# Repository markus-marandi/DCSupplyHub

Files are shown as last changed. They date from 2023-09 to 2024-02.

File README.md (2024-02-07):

# LAB DC POWER SUPPLY

## Overview

This repository is dedicated to the LAB DC POWER SUPPLY project, a comprehensive hardware solution designed to deliver a stabilized output adjustable between 0 and 30VDC with a current control range from 2 mA to 3 A.

## Key Features

- **Variable Control**: Delivering a continuously adjustable voltage between 0 to 30V and a current from 2 mA up to 3A.
- **Safety First**: Built-in overcurrent protection and short-circuit safeguards.
- **User-Friendly**: Dual LCD displays for real-time feedback, clear labeling, and precise control knobs.
- **Compact Design**: Optimized for benchtop use with dimensions.

## Documentation

For a detailed breakdown of the hardware requirements, specifications, component details, and more, refer to the [Hardware Requirements Specification](./documentation/SPECS) under the `documentation` directory.

## Components

Our project components are sourced from trusted suppliers including Farnell, TME, Mouser, and others. The list of components, along with their respective codes, can be found in the detailed specification document.

## Revision History

The project has undergone several revisions:

- **1.0** (18.09.2023): Initial Version.
- **1.1** (20.09.2023): GANTT chart.
- **1.2** (27.09.2023): Started documentation and specification.
- **1.3** (04.10.2023): Added component list.
- **1.4** (10.10.2023): Added schematics.
- **1.5** (15.10.2023): Added second version of schematics. 

For a detailed revision history, please refer to the specification document.

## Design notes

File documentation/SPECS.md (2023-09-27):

# LAB DC POWER SUPPLY
## Hardware Requirements Specification
### Version 1.1

---

### Revision History

| Date | Version | Description | Author |
|---|---|---|---|
| 18.09.2023 | 1.0 | Initial Version | Markus Marandi|
| 20.09.2023 | 1.1 | Added GANTT chart | Markus Marandi|

---

## Table of Contents

1. [Introduction](#introduction)
    - [Purpose](#purpose)
    - [Scope](#scope)
    - [Definitions, Acronyms, and Abbreviations](#definitions-acronyms-and-abbreviations)
2. [Overall Description](#overall-description)
    - [Product Perspective](#product-perspective)
    - [Product Functions and Components](#product-functions-and-components)
    - [Constraints](#constraints)
    - [Assumptions and Dependencies](#assumptions-and-dependencies)
3. [Specific Requirements](#specific-requirements)
    - [External Interface Requirements](#external-interface-requirements)
    - [Performance Requirements](#performance-requirements)
    - [Safety Requirements](#safety-requirements)
    - [Environmental Requirements](#environmental-requirements)
    - [Reliability and Durability](#reliability-and-durability)
4. [Flowchart](#flowchart)
5. [GANTT chart](#gantt-chart)

---

## 1. Introduction

This document provides a detailed technical specification for a 0-30 VDC Stabilised Power Supply with Current Control ranging from 2 mA to 3 A as a hardware project.

### 1.2 Purpose

The purpose of this specification is to offer a comprehensive and detailed description of the requirements for the 0-30V / 0-3A Bench Power Supply. It encapsulates its external behavior, functional requirements, design constraints, and other crucial details to ensure the successful design and execution of the hardware.

### 1.2 Scope

This hardware project centers on the 0-30V / 0-3A Bench Power Supply, a device proficient in delivering a continuously variable stabilized output adjustable between 0 and 30VDC. The power supply can modulate its output current from a minimal 2 mA to a maximum of 3A. This document encompasses the entirety of the hardware's functionalities, design considerations, and safety features.

### 1.3 Definitions, Acronyms, and Abbreviations

- **VDC**: Volts Direct Current
- **mA**: Milliamperes
- **A**: Amperes
- **PCB**: Printed Circuit Board
- **SRS**: Software Requirements Specification
- **PSU**: Power Supply Unit

---

## 2. Overall Description

### 2.1 Product Perspective

The 0-30V / 0-3A Bench Power Supply is envisioned to be a compact and efficient unit, suitable for diverse electronics testing and experimentation. The choice of a maximum 30V output ensures broader compatibility with prevalent electronics components and systems, simultaneously ensuring safety and affordability.

### 2.2 Product Functions and Components

- **Variable Voltage and Current Control**: Adjust the output voltage from 0 to 30V and the current from 2 mA to 3A.
- **LCD Displays**: Dual LCD displays for real-time voltage and current readings.
- **Control Knobs**: Precise control over voltage and current settings with digital potentiometers.
- **LED Indicator**: Signifies the operational status of the power supply.
- **Current Limiting and Short Circuit Protection**: Safeguards against overcurrent damage.
- **Power Switch**: An ON/OFF mechanism.
- **Microcontroller (ATmega32U4)**: Governs display and overall control.
- **Case**: Well-ventilated and heat-proof with anti-slippery feet.
- **Stadardised Connectors**: Banana plugs and binding posts.

### 2.3 Constraints

Approximate dimensions are 105 x 165 x 249 mm.

### 2.4 Assumptions and Dependencies

It's assumed that the device will be utilized in a dry environment.

---

## 3. Specific Requirements

### 3.1 External Interface Requirements

- **Input Interface**: TBD
- **Output Interface**: Connectors for DC output (0 – 30V, preferable up to 36V) and a USB connector (5V, 1A).
- **Display**: Dual-line for output voltage and current.

### 3.2 Performance Requirements

- **Voltage Stability**: Max ripple of 0.05%.
- **Current Limiting Accuracy**: Tolerance of ± 0.01A.

### 3.3 Safety Requirements

- **Overcurrent Protection**: Safeguard against potential overcurrent.
- **Thermal Management**: Prevent overheating.

### 3.4 Environmental Requirements

- **Operating Temperature**: Optimal between -10 to 40°C.
- **Humidity Tolerance**: Up to 80% relative humidity without condensation.

### 3.5 Reliability and Durability

- **Component Quality**: Ensure longevity and reliability.

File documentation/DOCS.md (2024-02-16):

### DC Supply Hub Documentation

#### Overview

The DC Supply Hub is designed to provide a configurable power supply, capable of adjusting voltage and current settings through user inputs. This system utilizes a microcontroller unit (MCU) interfaced with various components including digital potentiometers, digital-to-analog converters (DACs), and current sensors, to control and monitor the output power.

#### System Architecture

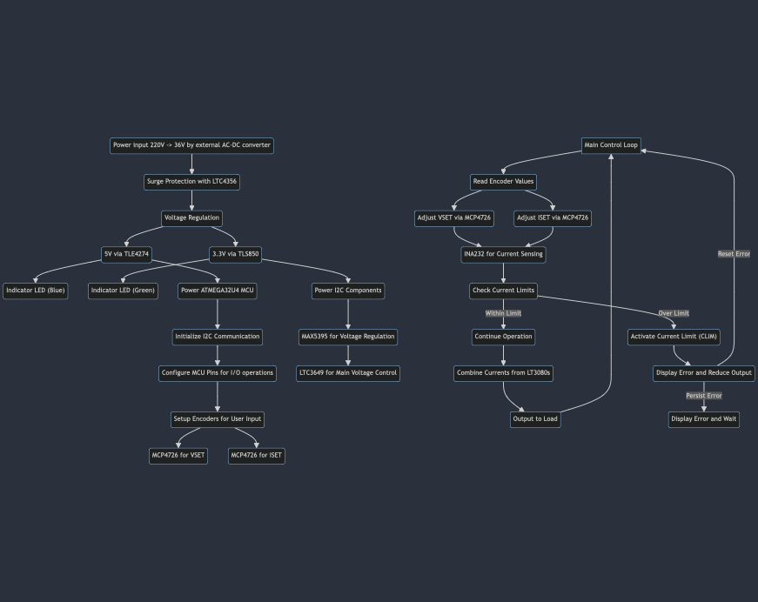
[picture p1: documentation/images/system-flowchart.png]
System Flowchart


**Components**
- **Microcontroller (MCU):** At the heart of the system is an ATMEGA32U4-AU MCU, responsible for coordinating the interactions between all peripherals and executing the firmware logic.
- **Digital Potentiometer (MAX5395NATA+T):** Used for fine-tuning the output voltage by adjusting the resistance in the feedback loop of an operational amplifier.
- **DACs (MCP4726):** Two DACs are used, one for setting the output voltage (VSET) and the other for setting the output current limit (ISET).
- **Current Sensor (INA232BIDDFR):** Provides accurate monitoring of the output current by measuring the voltage across a shunt resistor.
- **Encoders:** Two rotary encoders provide user inputs to set the desired voltage and current settings.

**I2C Addresses**
- 0x28: Digital potentiometer (MAX5395NATA+T) [U10].
- 0x30: Encoder values for voltage and current.
- 0x48: INA232BIDDFR (16-bit Current sensor).
- 0x60: MCP4726 (DAC for VSET) [U16].
- 0x63: MCP4726 (DAC for ISET) [U11].

**MCU logical I/O**
- PIN 1 (CLIM): Current limit indicator/output.
- PIN 28 (LED_MCU): LED indicator controlled by the MCU.
- PIN 36 (ADC-IOUT): Analog-to-digital converter input for measuring output current directly from the MCU.

#### Firmware Logic

Firmware Flowchart

The firmware controls the DC Supply Hub's operation, including reading encoder inputs for voltage and current settings, adjusting the output voltage and current accordingly, and monitoring the actual output current for safety and accuracy. The main components of the firmware logic include:

1. **Initialization:** Setup of I2C communication, DACs initialization, encoder input setup, and current sensor configuration.
2. **Input Processing:** Receives encoder inputs for desired voltage and current settings and updates the system settings accordingly.
3. **Output Adjustment:** Controls the digital potentiometer and DACs to adjust the output voltage and current settings based on user inputs.
4. **Current Monitoring:** Uses the INA232 current sensor to monitor the actual output current, ensuring it does not exceed the user-set limit.
5. **Safety Features:** Includes mechanisms to prevent overcurrent and overheating, such as dynamic current limiting and thermal shutdown.

#### Bill of Materials (BOM)

```markdown
| Component | Part Number | Description | Quantity |
|-----------|-------------|-------------|----------|
| D3 | SSB43L | 40V 0.45V 5A Schottky Barrier Diodes | 7 |
| ENC1, ENC2 | 440054-3 | 1x3P 2mm Male pin Wire To Board Connector | 10 |
| J2 | 2013499-1 | MICRO USB REC TYPE B DIP | 5 |
| J4 | 1757242 | 2 Bend 5.08mm 1x2P Pluggable Terminal Block | 5 |
| LED1 | CheckFuse | 0805 Red LED | 20 |
| LED2 | YELLOW | 0805 Yellow LED | - |
| LED3 | BLUE | 0805 Blue LED | - |
| LED7 | GREEN | 0805 Green LED | - |
| U5 | ATMEGA32U4-AU | 32KB Flash Microcontroller | 5 |
| D1, D2, D6 | CM1223-02SO | SOT-23-5 TVS | 15 |
| J3, J5, J6 | 61900411121 | 2x32P 2.54mm Plugin Connector | 15 |

```
### Programming the MCU

The MCU was programmed using Arduino's In-Circuit Serial Programming (ICSP) method, ensuring a reliable and efficient way to upload the firmware directly to the chip. This approach allows for direct programming of the MCU without the need for a pre-installed bootloader, providing more control over the hardware and enabling the use of the entire flash memory for the application code.

### Conclusion

The DC Supply Hub represents a sophisticated electronic design that integrates digital control with analog power management to provide a versatile and user-friendly power supply solution. The documentation provided outlines the system's architecture, key components, and firmware logic, providing a comprehensive overview for understanding and replicating the design.

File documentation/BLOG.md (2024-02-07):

# LAB DC POWER SUPPLY Development Blog

## 18.09.2023

- Created the initial version of Hardware Requirements Specification.
- Documented key features, requirements, and project scope.

## 20.09.2023

- Updated the Hardware Requirements Specification.
- Added a GANTT chart for project timeline visualization.

## 26.09.2023

- Researched FARNELL's catalogue and listed essential components.
- Finalized components' part numbers and estimated costs.

| Component | Farnell Part Number | Price (€) |
|---|---|---|
| Microcontroller (MCU) | 1748525 | €4.9 |
| 3.3V LDO Voltage Regulator | 1467779 | €0.7 |
| 5.0V LDO Voltage Regulator | 1467781 | €0.5 |
| 16MHz Crystal Oscillator | 1611806 | €0.8 |
| Push Buttons | 1821244 | €0.5 |
| Electrolytic Capacitors | 1217619, 4434778, 8767432 | €4-7 |
| Ceramic capacitors | 2320821, 1759057, 1520289 | €1-2 |
| Diodes | 2118071, 1462392, 2329772, 3230195, 1634076 | €5-7 |
| Dual LCD Display (16 x 2)  | 2675047, 2125942 | €2-4 |
| Rotary Encoders | 3769973 | €11 |
| LED Indicator, heat sink | 2065054 | €5.2 |
| Resistors | 2112111 | €6 |
| **Total** | | **€45** |

## 27.09.2023

- Initialized a GitHub repository for the project.
- Added Hardware Requirements Specification, README, and this development blog.

## 01.10.2023

- Started with initial schematics design. 
- Searched for previously used libraries and components which are available in Delta.

## 04.10.2023

- Continued with schematics design.

## 10.10.2023

- Finished the initial schematics and ready for review.

## 15.10.2023

- Added II version of schematics with significant improvements and fixes.

## 20.10.2023
- Started with PCB design.

## 25.10.2023
- Continued with PCB design.

## 30.10.2023
- Made modifications to schematics based on PCB design requirements.

## 05.11.2023
- Removed some unnecessary components from the schematics.
- Started with the second version of PCB design.

## 10.11.2023
- Continued with PCB design.

## 15.11.2023
- Made more modifications to the schematics based on the second version of PCB design.
- Thought about head dissipation and started with 3D modeling.

## 20.11.2023
- Continued with the PCB design.

## 01.12.2023
- Finished the PCB design and ready for review.

## 05.12.2023
- Made modifications to PCB design. 

## 10.12.2023
- Ordered components that were missing

## 27.12.2023

- Started 3D modeling, focusing on designing an enclosure that would provide adequate cooling and easy access to the power supply's interfaces.

## 29.12.2023

- Refined the design of the enclosure, adding support structures for internal components and ensuring the model was optimized for 3D printing.

## 02.01.2024

- Began the soldering process, focusing on the precision placement of microcontroller and power regulation components.

## 04.01.2024

- Continued with soldering, addressing the more complex sections involving the analog circuitry and ensuring all connections were solid for optimal performance.

## 06.01.2024

- Completed the soldering of all components. Performed inspection to identify any potential solder bridges or cold joints.

## 03.01.2024

- Initiated the 3D printing process. The first print was a prototype to test fit and identify any adjustments needed for the enclosure design. Had to reprint the enclosure due to a few minor issues.

## 05.01.2024

- Made necessary adjustments to the 3D model based on the prototype test fit. Reprinted the enclosure with the modifications to ensure fit for all internal components.

## 17.01.2024

- Began programming the microcontroller, implementing the initial firmware setup and focusing on basic power output control functionalities. Had to debug initially MCU because of cold solder joints.

## 20.01.2024

- Implemented controlling logic features in the firmware, such as overcurrent protection and voltage control. 
- Added a feature to display the current and voltage on the LCD display.
- Found out that displays are not I2C compatible and had to be solved with a digital interface.

## 24.01.2024

- Debugged the firmware, identifying bugs and areas for improvement in the control logic.
- Started testing the power supply with a dummy load to verify the output voltage and current regulation but it failed. 

## 27.01.2024

- Made more firmware adjustments to fix the issues with the power supply's output regulation.

## 31.01.2024

- Started the debugging process, going through the code and trying to identify the root cause of the power supply's output regulation issues.

## 06.02.2024
- Found out that the issue was in the current measurement and regulation part of the circuit.
- Made a document for important I2C components and their addresses.
- Made a document for the conclusion and improvements.
---

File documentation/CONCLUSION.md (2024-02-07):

# Project Considerations and Improvements

Here are concluded several key considerations and suggests improvements for the current and future design iterations of the project.

## Power Conversion Efficiency

### LDO Usage for 36V to 5V Conversion

- **Current Implementation**: The project currently uses a TLE4274 LDO for converting 36V to 5V, resulting in a power dissipation of 12.4W, which is highly inefficient and leads to unnecessary thermal management issues.
- **Why It's Problematic**: The high power dissipation is due to the large voltage drop across the LDO and its linear regulation nature, which inherently suffers from poor efficiency in high voltage drop applications.
- **Suggestion**: Consider switching to a switch-mode power supply (SMPS) design. A component such as the LM2678 from Texas Instruments, which is designed to efficiently convert high input voltages (up to 40V) to lower output voltages, can significantly reduce power dissipation. For example, converting 36V to 5V with an SMPS could bring efficiency above 90%, dramatically reducing power dissipation.

### TLS850 for 36V to 3.3V Conversion

- **Current Situation**: Using the TLS850 to convert 36V to 3.3V dissipates about 1.4W, which is more efficient compared to the 5V conversion but still has room for improvement.
- **Improvement Suggestion**: While the TLS850 performs relatively well, evaluating alternative SMPS solutions that offer even higher efficiency or better thermal performance could further optimize power usage and minimize dissipation.

## Programming and Control

### Microcontroller Choice

- **Observation**: The current choice of MCU does not support extensive libraries for easy programming.
- **Suggestion**: For future designs, consider using an ESP32-based module. ESP32 modules come with extensive support and libraries for a wide range of applications, significantly easing the programming effort and reducing development time.

### Digital Potentiometer Use

- **Current Method**: The project controls the LTC3649 with a MAX5395 digital potentiometer.
- **Issues**: This approach might not offer the best precision and flexibility needed for optimal control.
- **Alternative**: A better alternative could be using a microcontroller with DAC outputs to directly control the LTC3649. This method would allow for more precise control, easier calibration, and potentially reduce component count.

## Current Measurement and Regulation

### Current Comparators

- **Current Approach**: Using current comparator for current limiting. 
- **Drawbacks**: This method can be less accurate and more prone to noise, leading to stability issues.
- **Alternative**: Use dedicated current sense amplifiers or integrated power management ICs that offer higher accuracy, built-in filtering, and easier integration. These components can improve reliability and performance in critical applications.

### LT3080 for Current Addition

- **Implementation**: The project uses three LT3080 regulators for current adding to the voltages.
- **Consideration**: While functional, this setup might not be the most efficient or cost-effective.
- **Suggestion**: Investigate integrated power modules or multi-channel power management ICs that can handle multiple outputs with current sharing. These solutions could simplify the design, improve efficiency, and potentially lower overall cost.

## PCB Design

### Attachment Holes

- **Current Design**: The PCB lacks attachment holes.
- **Improvement**: Including attachment holes in the PCB design can significantly enhance the mechanical stability and ease of installation. It's a simple addition that can prevent potential issues related to mechanical stress and alignment in the final assembly.

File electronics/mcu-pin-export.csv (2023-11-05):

# Altium Pin Report File
Pin Designator | Net Name | Display Name | IO Bank | IO Standard | Slew Rate | Drive Strength | IO Pin | Vref Pin | CLK Pin | Config Pin | Special Pin | Group | Differential Pair
1 |  | PE6
2 | VCC | UVCC
3 | D-_N | D-
4 | D+_N | D+
5 | GND | UGND
6 | UCAP | UCAP
7 | VCC | VBUS
8 |  | PB0
9 |  | PB1
10 |  | PB2
11 |  | PB3
12 |  | PB7
13 | RESET | R\E\S\E\T\\
14 | VCC | VCC_2
15 | GND | GND_2
16 | XTAL2 | XTAL2
17 | XTAL1 | XTAL1
18 | SCL | PD0
19 | SDA | PD1
20 | PWM_OUT(Current Set) | PD2
21 | PWM_OUT(Voltage Set) | PD3
22 | 7 | PD5
23 | GND | GND_3
24 | VCC | AVCC_2
25 | ON/OFF | PD4
26 |  | PD6
27 |  | PD7
28 | CC | PB4
29 | CV | PB5
30 | OUT | PB6
31 |  | PC6
32 |  | PC7
33 |  | PE2
34 | VCC | VCC
35 | GND | GND_4
36 |  | PF7
37 |  | PF6
38 |  | PF5
39 | I_OUT_SENSE | PF4
40 | V_OUT_SENSE | PF1
41 | V_IN_SENSE | PF0
42 | NetC34_1 | AREF
43 | GND | GND
44 | VCC | AVCC

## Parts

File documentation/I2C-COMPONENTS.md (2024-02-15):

# I2C Communication Documentation

### Following components are connected to the I2C bus:

### 1. [MAX5395NATA+T](https://www.farnell.com/datasheets/2297485.pdf) - Digital Potentiometer (U10)
- **Purpose**: Controls I_SET for LTC3649.
- **I2C Address**: Configurable based on the ADDR0 pin setting:
  - `0x28` (ADDR0 = GND)
- **Operation**:
  - Supports both read and write operations.
  - Utilizes an 8-bit command structure for adjusting wiper positions and configuration settings.

### 2. [MCP4726](https://ww1.microchip.com/downloads/aemDocuments/documents/OTH/ProductDocuments/DataSheets/22272C.pdf) (U16, U11) - DAC for VSET and ISET Control (x2)
- **Purpose**: Provides analog output for VSET and ISET control.
- **I2C Address**: `0x60` (default). Address can be altered via the A0 pin for using multiple devices on the same bus.
  - **U11 - 0x63**
  - **U16 - 0x60**
- **Operation**:
  - Operates as a slave device.
  - Supports standard, fast, and high-speed modes.
  - Writing and reading operations adhere to the I2C protocol with specific command/data formats.

### 3. [INA232](https://www.ti.com/lit/ds/symlink/ina232.pdf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) (U7)- 16-bit Current Sensor
- **Purpose**: Measures current with high precision.
- **I2C Address**: `0x48` (checked).
- **I2C Operatios**:

## Non-I2C Component

### [DFROBOT DFR0645-R](https://www.farnell.com/datasheets/3708797.pdf) (J6, I3) - 4-Digital LED Segment Display Module
- **Note**: These modules are not compatible with I2C communication due to design limitations that cause them to occupy the entire I2C bus. They must be operated using a digital interface.

## Programming Considerations

- **Unique I2C Addresses**: Ensure each device on the I2C bus has a unique address to prevent conflicts.
- **Data Transfer Protocol**:
  - **Start Condition**: Signal the beginning of an I2C communication session.
  - **Slave Addressing**: Followed by the R/W bit to indicate read or write operation.
  - **Write Operation**:
    - Send the command byte followed by data bytes.
    - Each byte transmitted must be acknowledged by the receiver.
  - **Read Operation**:
    - Send the command byte to specify the register to read from.
    - Issue a repeated START condition and transmit the slave address with the read bit.
    - Receive data bytes, acknowledging after each byte, except for the last one.
  - **Stop Condition**: Marks the end of an I2C communication session.
- **Device-Specific Commands**: Consult each component's datasheet for detailed information on command structures, operational modes, and configurations.

## Note on DFROBOT DFR0645-R

The DFROBOT DFR0645-R modules require digital signals for operation and cannot share the I2C bus with other devices due to their design. Allocate separate digital pins for these modules when integrating them into systems that also use I2C communication.

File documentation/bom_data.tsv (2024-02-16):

D3 | SSB43L | DO-214AA(SMB) | SSB43L-E3/52T | C5338051 | 40V 0.45V 5A DO-214AA Schottky Barrier Diodes (SBD) ROHS | 7
ENC1,ENC2 | 440054-3 | SHDR3W50P0X200_1X3_800X470X635P | 440054-3 | C486256 | 1x3P 1 2mm Male pin 3 Straight Plugin,P=2mm Wire To Board / Wire To Wire Connector ROHS | 10
J2 | 2013499-1 | 2013499-1 | 2013499-1 | C5163346 | USB Connectors MICRO USB REC TYPE B DIP ASSY(AU) | 5
J4 | 1757242 | 1757242 | 1757242 | C90074 | 2 Bend 1 5.08mm 1x2P Green Board Edge/Receptacle-Close Push-Pull,P=5.08mm Pluggable System Terminal Block ROHS | 5
LED1 | CheckFuse | LED_SMD_0805_R | NCD0805R1 | C84256 | Colorless transparence 67mcd~195mcd -30℃~+85℃ 615nm~630nm Red 130° 65mW 0805 Light Emitting Diodes (LED) ROHS | 20
LED2 | YELLOW | LED_SMD_0805_R | NCD0805R1 | C84256 | Colorless transparence 67mcd~195mcd -30℃~+85℃ 615nm~630nm Red 130° 65mW 0805 Light Emitting Diodes (LED) ROHS
LED3 | BLUE | LED_SMD_0805_R | NCD0805R1 | C84256 | Colorless transparence 67mcd~195mcd -30℃~+85℃ 615nm~630nm Red 130° 65mW 0805 Light Emitting Diodes (LED) ROHS
LED7 | GREEN | LED_SMD_0805_R | NCD0805R1 | C84256 | Colorless transparence 67mcd~195mcd -30℃~+85℃ 615nm~630nm Red 130° 65mW 0805 Light Emitting Diodes (LED) ROHS
U5 | ATMEGA32U4-AU | QFP80P1200X1200X120-44N | ATMEGA32U4-AU | C44854 | 32KB 2.7V~5.5V AVR 2.5KB 16MHz FLASH 26 QFP-44(10x10) Microcontroller Units (MCUs/MPUs/SOCs) ROHS | 5
D1,D2,D6 | CM1223-02SO | SOT95P280X145-5N | CM1223-02SO | C890511 | 8.8V 6V 3.3V SOT-23-5 TVS ROHS | 15
J3,J5,J6 | 61900411121 | SHDR4W64P0X254_1X4_1020X580X1175P | 1125-2232G0S395C001 | C920766 | 3A Straight Square Pins 64P -40℃~+105℃ 2.54mm 双排 Black 2x32P 2.54mm Plugin,P=2.54 | 15

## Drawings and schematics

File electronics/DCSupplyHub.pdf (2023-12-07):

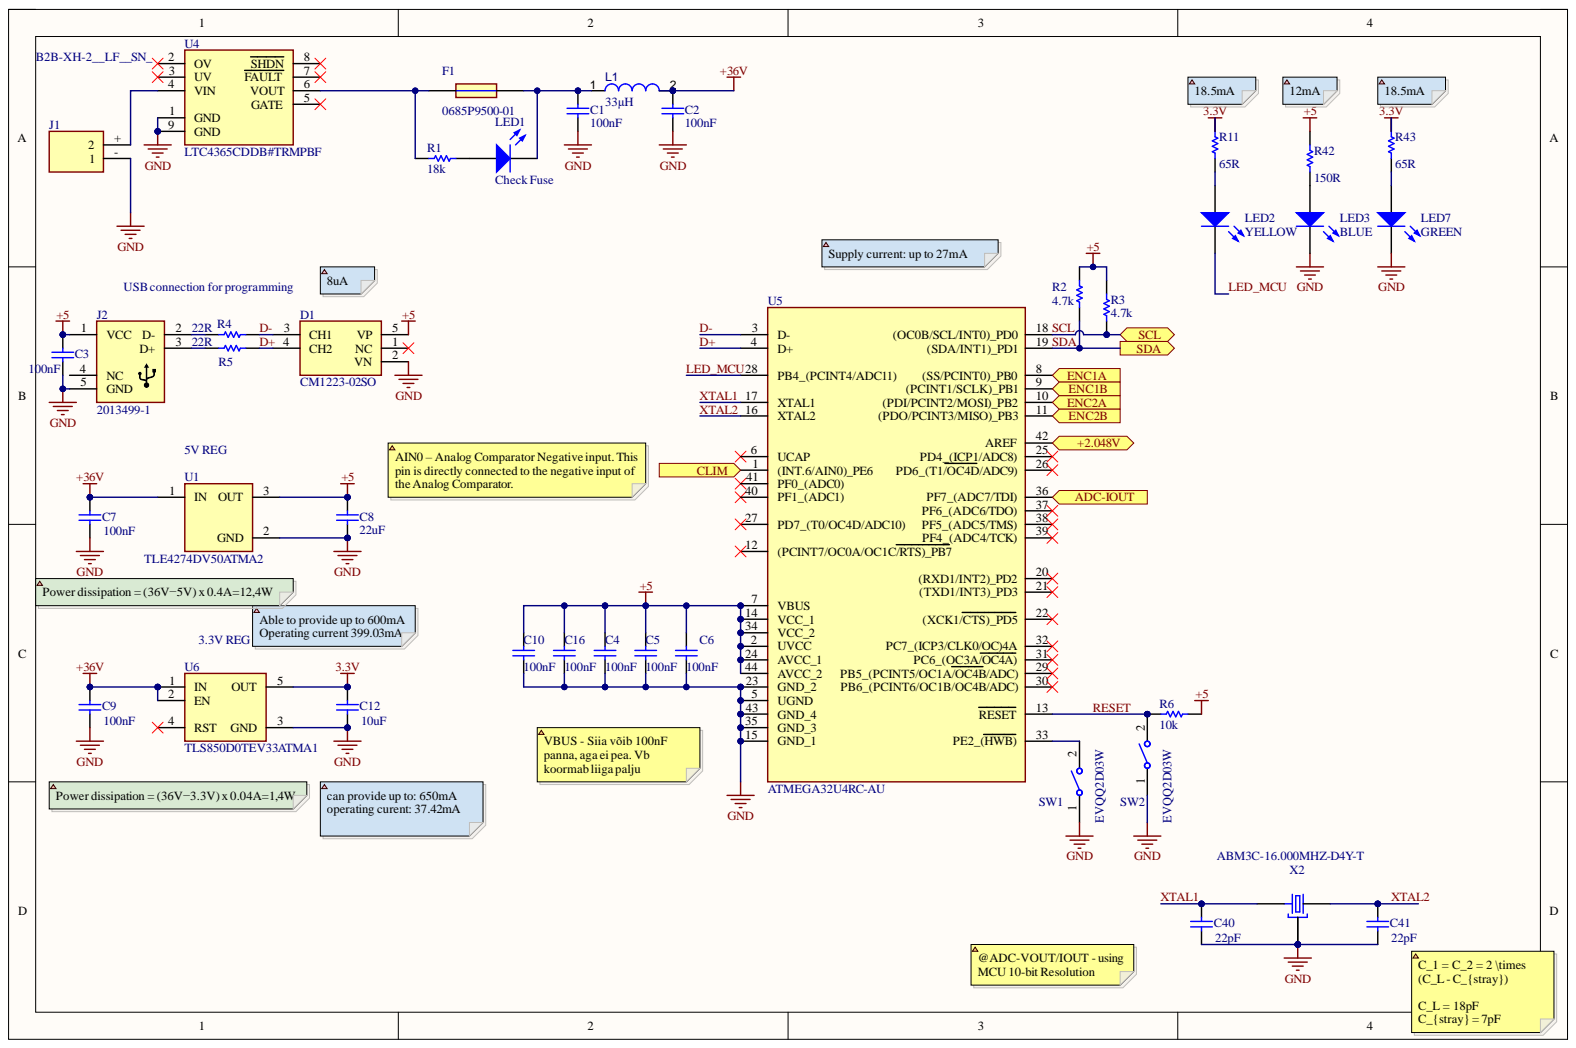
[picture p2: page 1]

Supply current: up to 27mA

AIN0 – Analog Comparator Negative input. This
pin is directly connected to the negative input of
the Analog Comparator.

VCC_1 14

Able to provide up to 600mA
Operating current 399.03mA

C10 | UVCC 2

VBUS - Siia võib 100nF
panna, aga ei pea. Vb
koormab liiga palju

can provide up to: 650mA
operating curent: 37.42mA

@ADC-VOUT/IOUT - using
MCU 10-bit Resolution

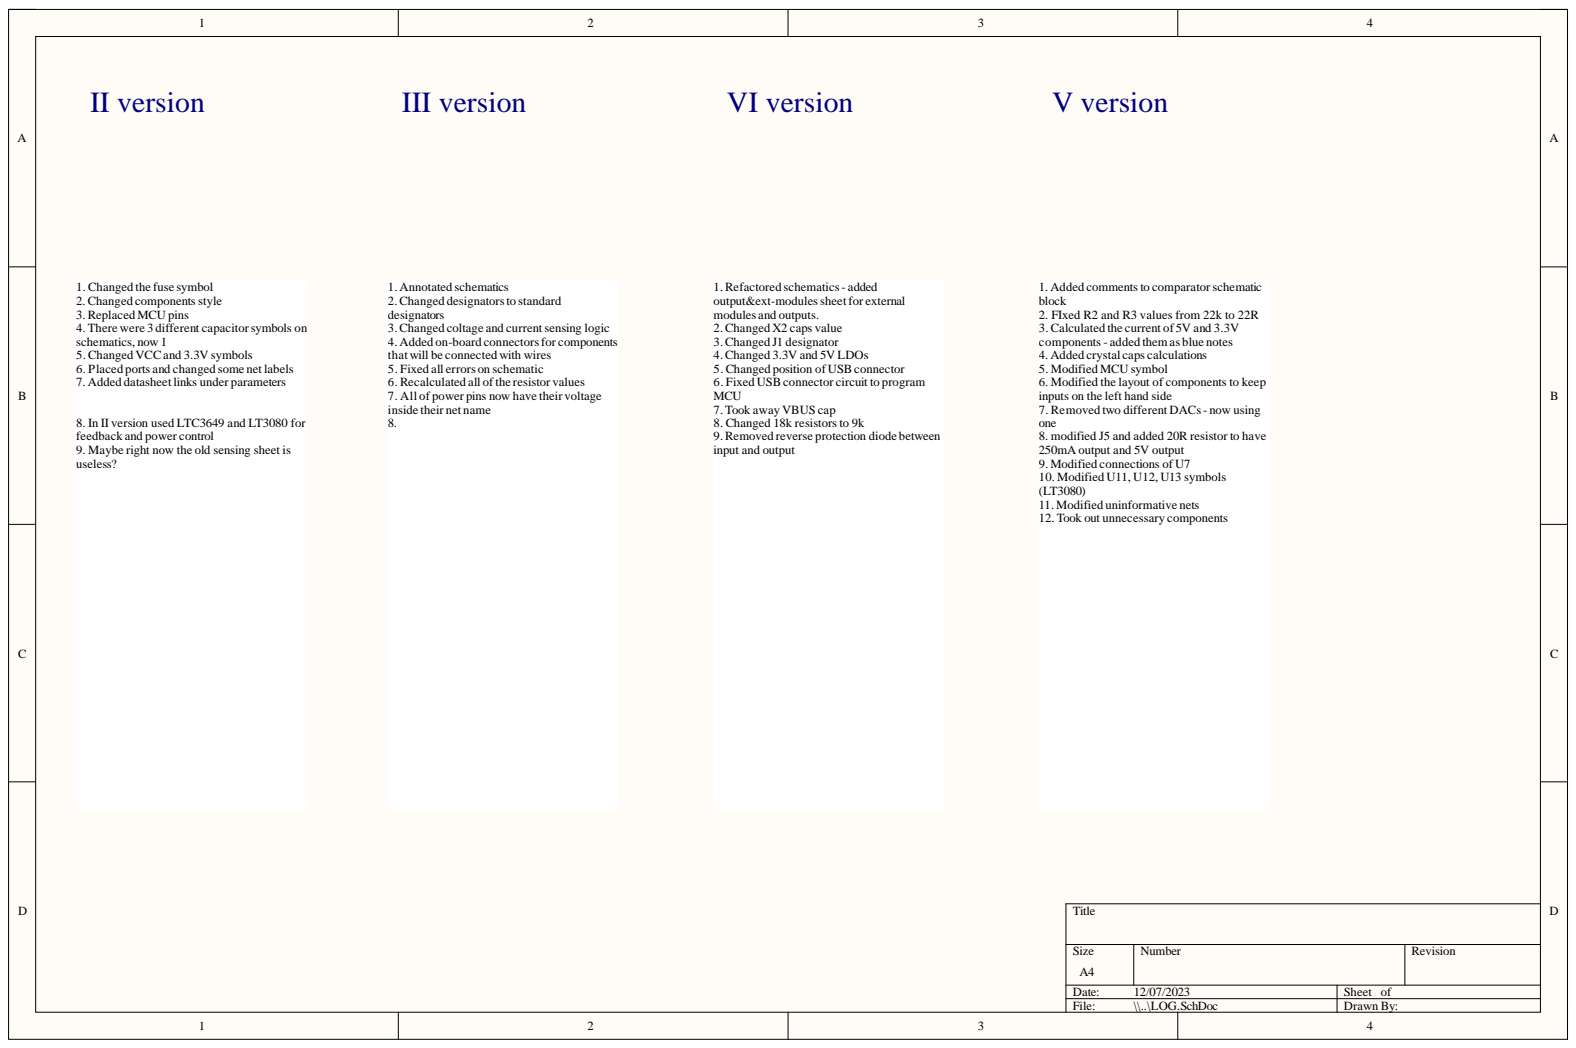
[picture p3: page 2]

1. Changed the fuse symbol
2.Changed components style
3.Replaced MCU pins
4. There were 3 different capacitorsymbols on
schematics, now 1
5. Changed VCCand 3.3V symbols
6. Placed ports and changed some net labels
7. Added datasheet links under parameters

1. Annotated schematics
2.Changed designators to standard
designators
3.Changed coltage and current sensing logic
4. Added on-board connectors for components
that will be connected with wires
5. Fixed all errors on schematic
6. Recalculated all ofthe resistor values
7. All of power pins now have their voltage
inside their net name

1.Refactored schematics - added
output&ext-modules sheet for external
modules and outputs.
2.Changed X2 caps value
3.Changed J1 designator
4.Changed 3.3V and 5V LDOs
5. Changed position of USBconnector
6. Fixed USBconnector circuit to program
MCU
7. Took away VBUS cap
8. Changed 18k resistors to 9k
9.Removed reverse protection diode between
input and output

1. Added comments to comparatorschematic
block
2. FIxed R2 and R3 values from 22k to 22R
3. Calculated the current of 5V and 3.3V
components - added them as blue notes
4. Added crystal caps calculations
5. Modified MCU symbol
6. Modified the layout of components to keep
inputs on the left hand side
7. Removed two different DACs - now using
one
8. modified J5 and added 20R resistor to have
250mA output and 5V output
9. Modified connections of U7
10. Modified U11, U12, U13 symbols
11. Modified uninformative nets
12. Took out unnecessary components

8. In II version used LTC3649 and LT3080 for
feedback and power control
9. Maybe right now the old sensing sheet is
useless?

Size A4 | Number | Revision

Date: 12/07/2023 | Sheet of
File: \\..\LOG.SchDoc | Drawn By:

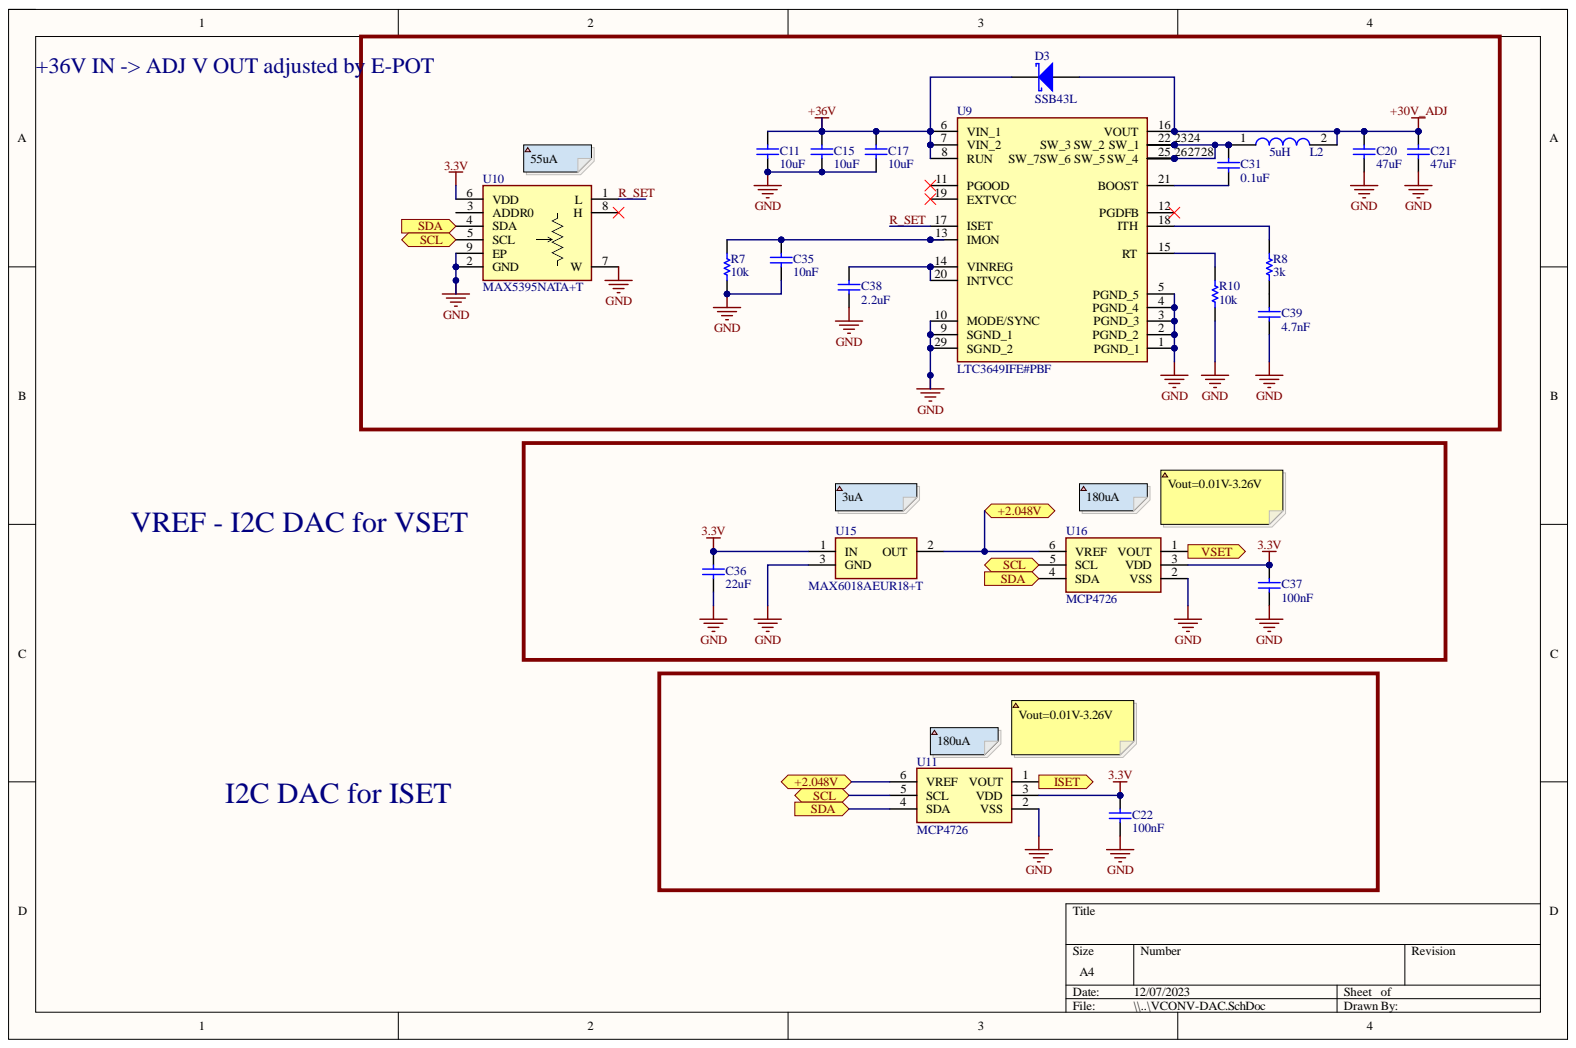
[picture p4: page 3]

+36V IN -> ADJ V OUT adjusted by E-POT

VREF - I2C DAC for VSET

Size A4 | Number | Revision

Date: 12/07/2023 | Sheet of
File: \\..\VCONV-DAC.SchDoc | Drawn By:

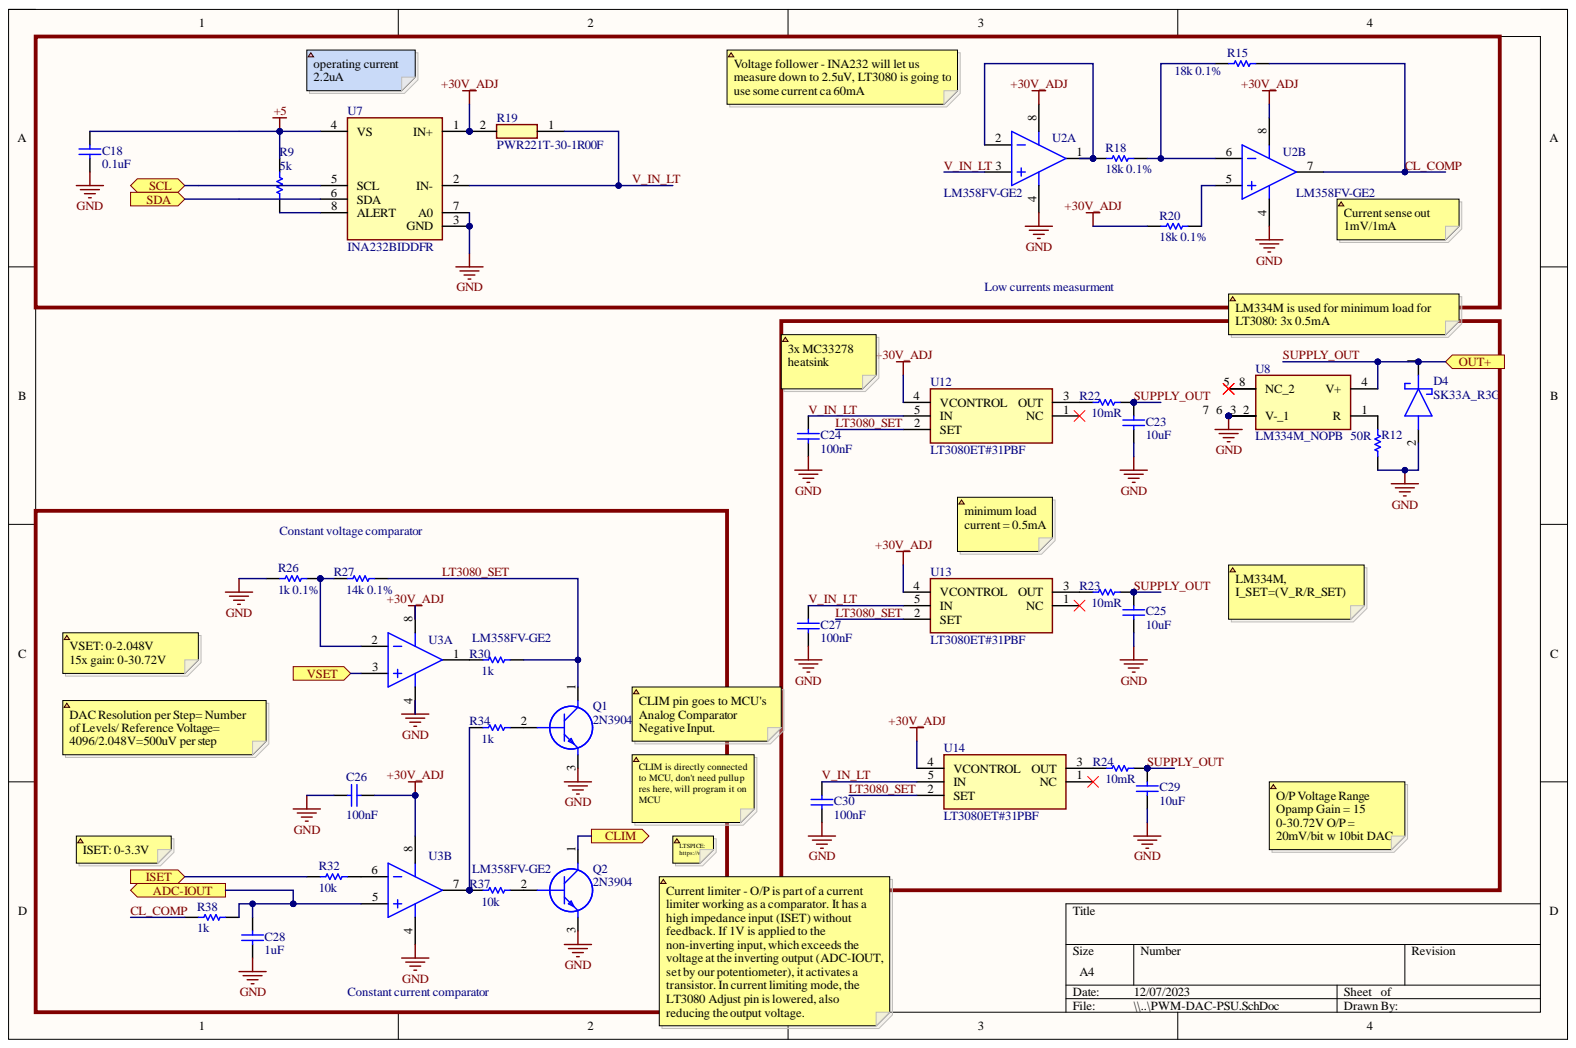
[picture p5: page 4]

Voltage follower - INA232 will let us
measure down to 2.5uV, LT3080 is going to
use some current ca 60mA

LM334M is used for minimum load for

CLIM pin goes to MCU's
Analog Comparator
Negative Input.

DACResolution per Step= Number
of Levels/ Reference Voltage=
4096/2.048V=500uV perstep

CLIM is directly connected
to MCU, don't need pullup

Current limiter - O/P is part of a current
limiter working as a comparator. It has a
high impedance input (ISET) without
feedback. If 1V is applied to the
non-inverting input, which exceeds the
voltage at the inverting output (ADC-IOUT,
set by our potentiometer), it activates a
transistor. In current limiting mode, the
LT3080 Adjust pin is lowered, also
reducing the output voltage.

Size A4 | Number | Revision

Date: 12/07/2023 | Sheet of
File: \\..\PWM-DAC-PSU.SchDoc | Drawn By:

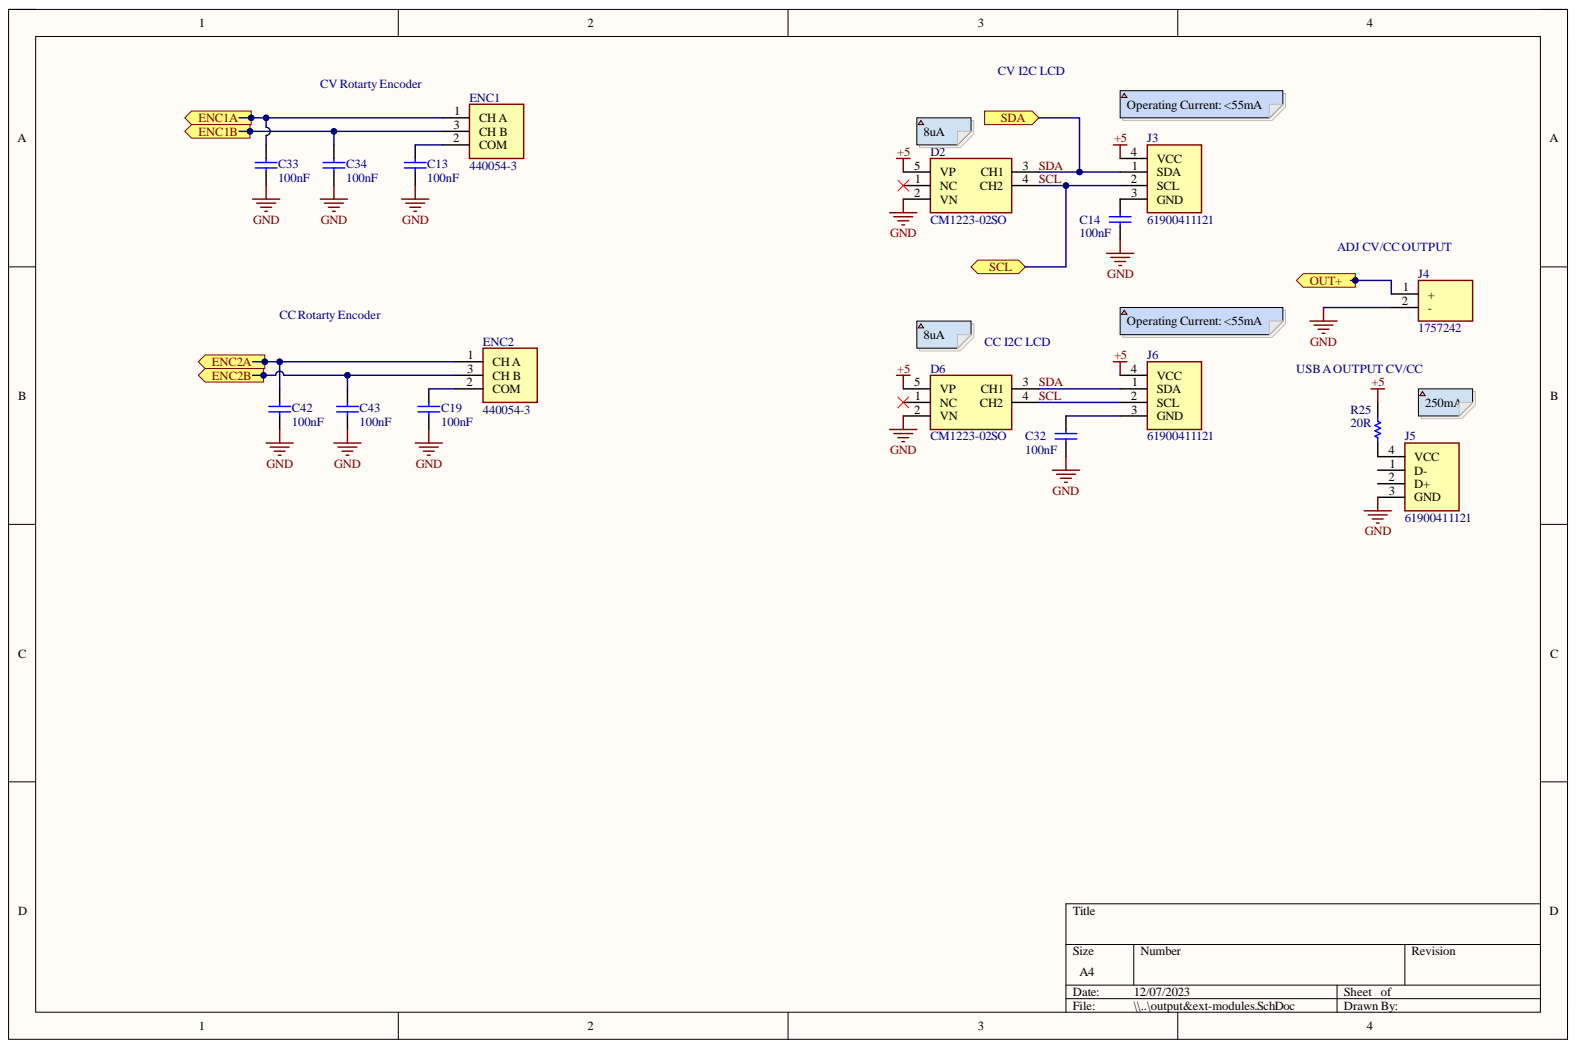
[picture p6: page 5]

Siz e A4 | Numb e r | R evisio n

Da te : 12/07/20 2 3 | She et of
File : \\. .\output&ext-module s . S c hD o c | Dr awn B y :

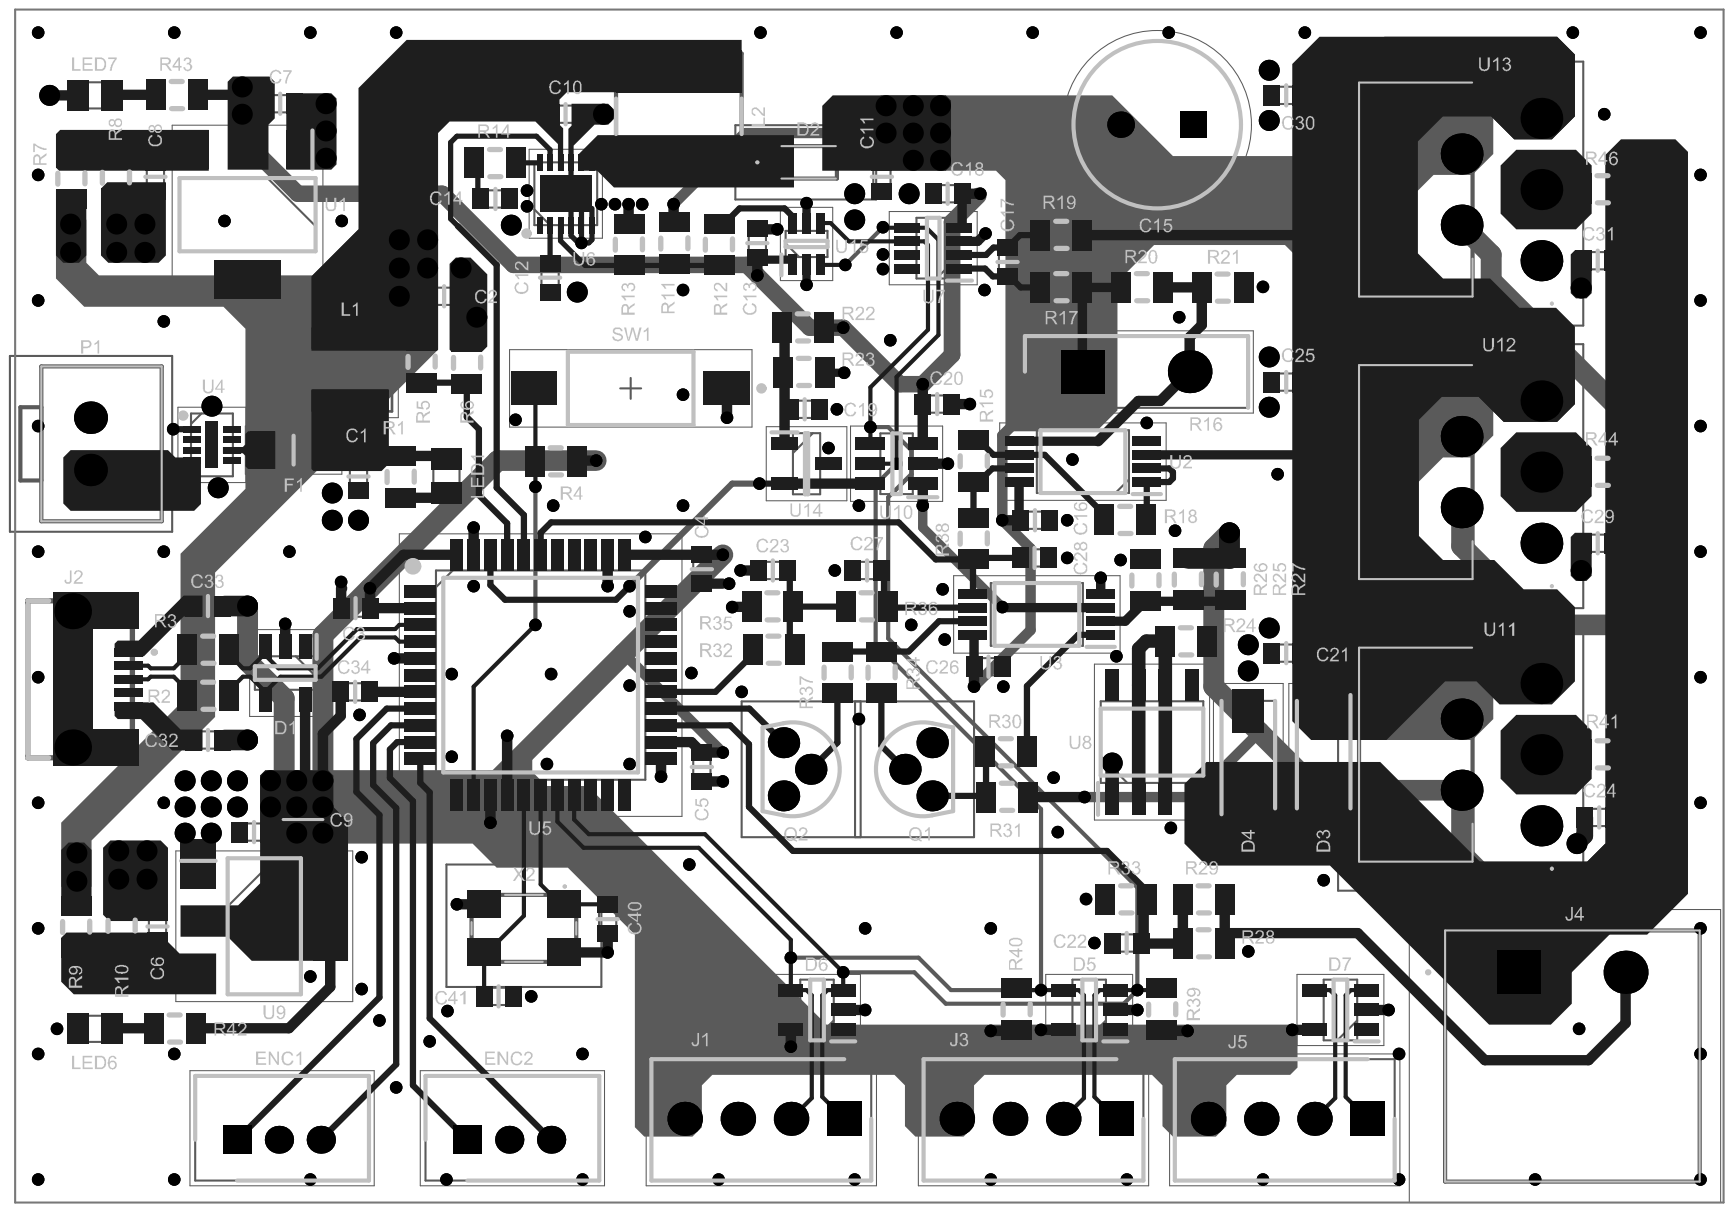
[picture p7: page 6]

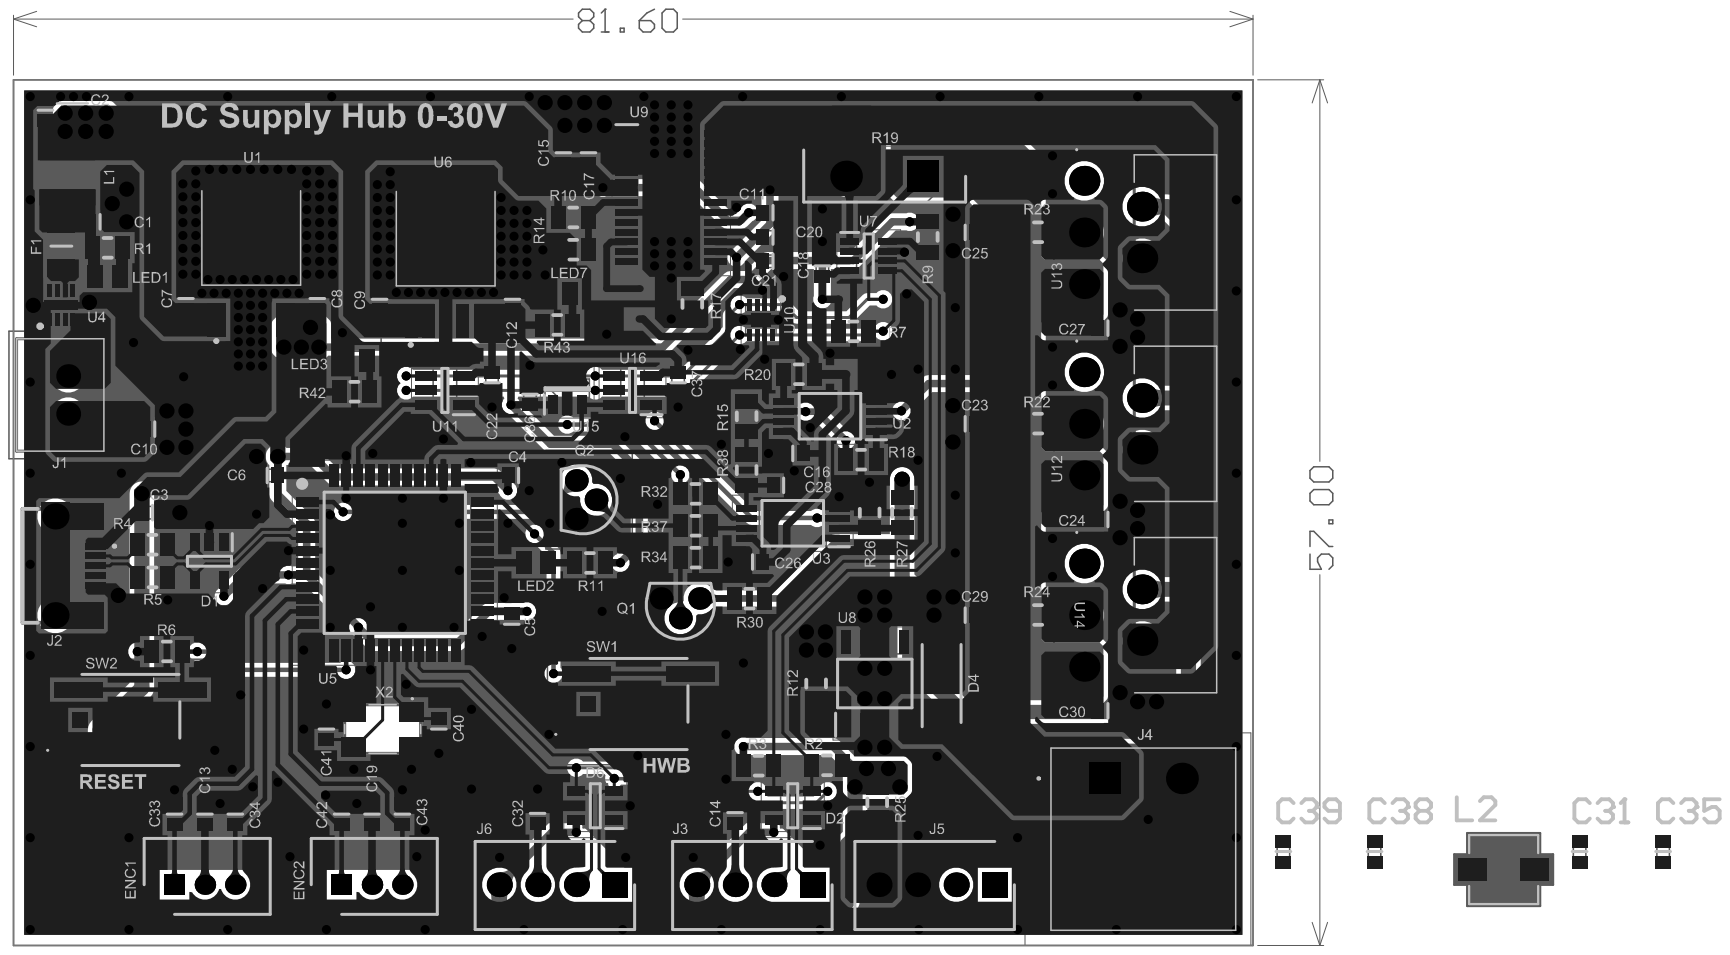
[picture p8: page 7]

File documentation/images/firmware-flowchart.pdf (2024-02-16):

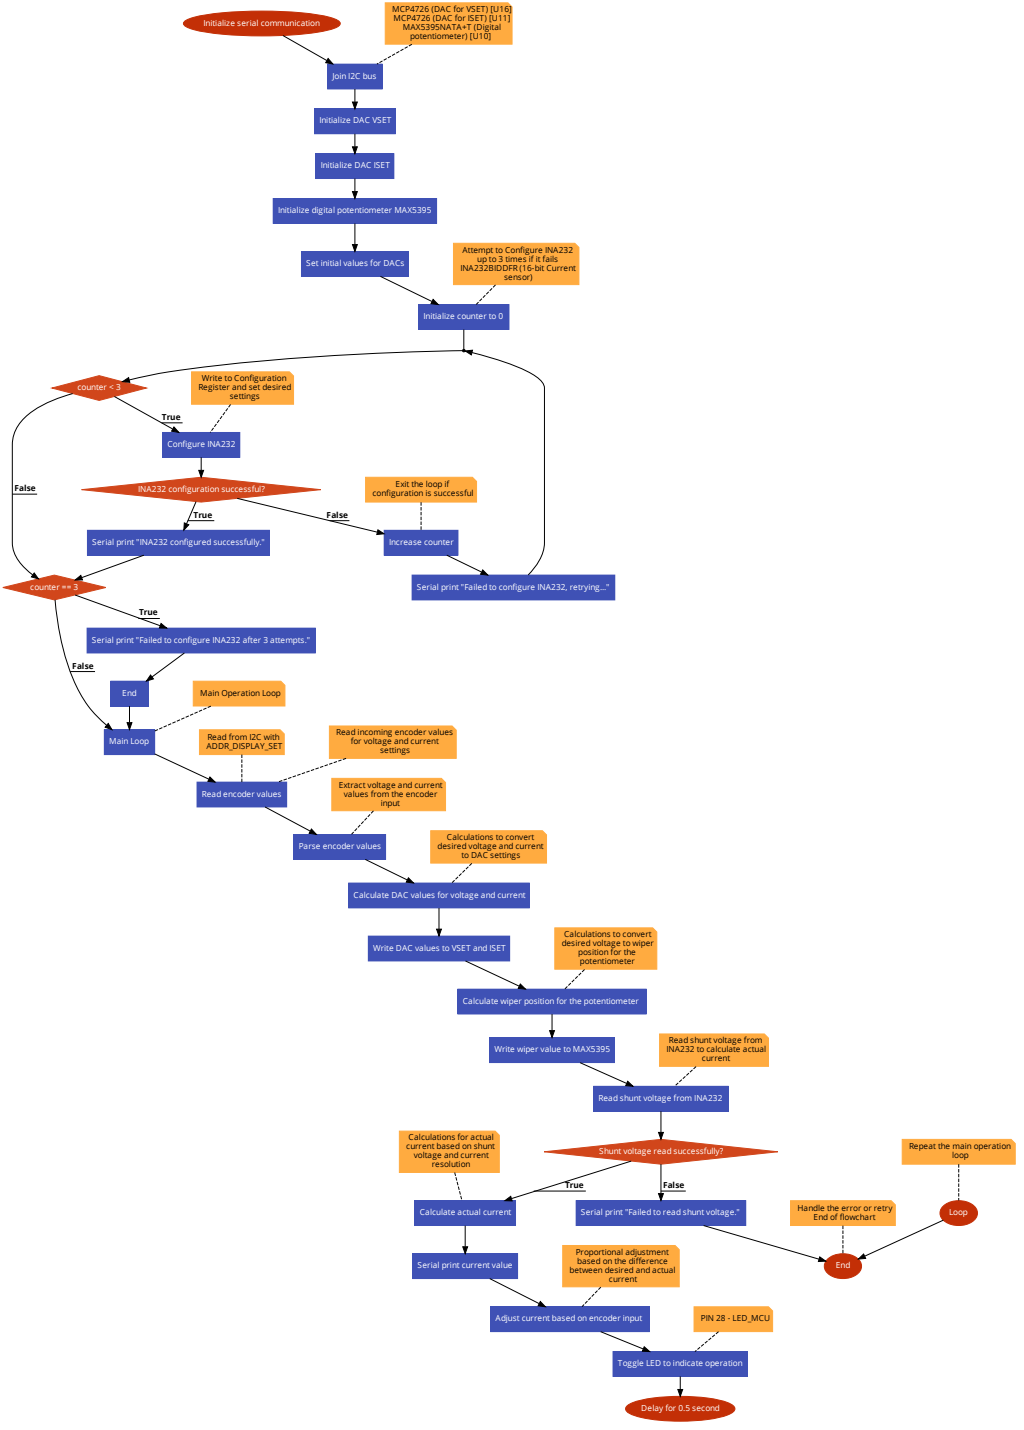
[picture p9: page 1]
Join I2C bus; counter < 3; Configure INA232; True; counter == 3; False; INA232 configuration successful?; Increase counter; Main Loop; End; Loop; loop; PIN 28 - LED_MCU; input; sensor); current

MCP4726 (DAC for VSET) [U16]
MCP4726 (DAC for ISET) [U11]
MAX5395NATA+T (Digital
potentiometer) [U10]

Initialize serial communication

Initialize DAC VSET

Initialize DAC ISET

Initialize digital potentiometer MAX5395

Attempt to Configure INA232
up to 3 times if it fails
INA232BIDDFR (16-bit Current

Set initial values for DACs

Initialize counter to 0

Write to Configuration
Register and set desired
settings

Exit the loop if
configuration is successful

Serial print "INA232 configured successfully."

Serial print "Failed to configure INA232, retrying..."

Serial print "Failed to configure INA232 after 3 attempts."

Main Operation Loop

Read incoming encoder values
for voltage and current

Read from I2C with
ADDR_DISPLAY_SET

Extract voltage and current
values from the encoder

Read encoder values

Calculations to convert
desired voltage and current
to DAC settings

Parse encoder values

Calculate DAC values for voltage and current

desired voltage to wiper
position for the
potentiometer

Write DAC values to VSET and ISET

Calculate wiper position for the potentiometer

Read shunt voltage from
INA232 to calculate actual

Write wiper value to MAX5395

Read shunt voltage from INA232

Calculations for actual
current based on shunt
voltage and current
resolution

Repeat the main operation

Shunt voltage read successfully?

Handle the error or retry
End of flowchart

Calculate actual current

Serial print "Failed to read shunt voltage."

Proportional adjustment
based on the difference
between desired and actual

Serial print current value

Adjust current based on encoder input

Toggle LED to indicate operation

Delay for 0.5 second

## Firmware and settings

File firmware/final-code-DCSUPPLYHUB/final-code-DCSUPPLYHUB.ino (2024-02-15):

/*
I2C addresses
- 0x28 - MAX5395NATA+T (Digital potentiometer) [U10]
- 0x30 - incoming encoder values for voltage and current
- 0x48 - INA232BIDDFR (16-bit Current sensor)
- 0x60 - MCP4726 (DAC for VSET) [U16]
- 0x63 - MCP4726 (DAC for ISET) [U11]

MCU logical I/O
- PIN 1 - CLIM
- PIN 28 - LED_MCU
- PIN 36 - ADC-IOUT

*/

// https://app.code2flow.com/Dm8F9oMX7uvp


#include <Wire.h>
#include <Adafruit_MCP4725.h>

// Define I2C addresses
#define ADDR_DISPLAY_SET 0x30
#define ADDR_DAC_VSET 0x60
#define ADDR_DAC_ISET 0x63
#define ADDR_MAX5395 0x28
#define INA232_ADDRESS 0x48
#define SHUNT_VOLTAGE_REG 0x01
#define SHUNT_CURRENT_REG 0x04

// Define MCU logical I/O pins
#define PIN_CLIM 1
#define PIN_LED_MCU 28
#define PIN_ADC_IOUT 36

// INA232 Registers
#define INA232_CONFIG 0x00
#define INA232_SHUNT_VOLTAGE 0x01

// Global variable for current resolution (1mV/A in this case)
float currentResolution = 0.001;  // You can change this value as needed
float Kp = 1;                     //tunable parameter that determines how aggressively the system responds to the difference between the desired and actual currents


// Global variable to hold the current DAC setting for ISET
int isetDacValue = 0;  // Initialize to 0 or appropriate value based on your system requirements


// Initialize DAC objects
Adafruit_MCP4725 dacVset;
Adafruit_MCP4725 dacIset;


// Define constants for voltage and current calculation
const float biasCurrent = 50e-6;       // 50µA bias current
const float maxResistance = 100000.0;  // 100kΩ, max resistance of the digital pot
const int maxWiperPosition = 255;      // MAX5395 has 256 positions, 0-255
const float MAX_CURRENT = 3.00;

// Constants for the DACs
const float VREF = 2.048;                              // Reference voltage for MCP4726 is 2.048V
const int DAC_RESOLUTION = 4096;                       // MCP4726 is a 12-bit DAC, so it has 4096 levels
const float VOLTAGE_PER_STEP = VREF / DAC_RESOLUTION;  // Voltage per step for the DAC

volatile float encoder_voltage = 0.0;
volatile float encoder_current = 0.0;

// Get values from encoders
void receiveEvent(int bytes) {
  String receivedData = "";
  while (Wire.available()) {
    char c = Wire.read();  // receive byte as a character
    receivedData += c;
  }

  // Parse the incoming string format "0.5 A, 2.5 V"
  int separatorIndex = receivedData.indexOf('A');
  if (separatorIndex != -1) {
    // Create substrings for current and voltage
    String currentStr = receivedData.substring(0, separatorIndex);
    String voltageStr = receivedData.substring(separatorIndex + 2, receivedData.indexOf('V'));

    // Trim whitespace from the substrings
    currentStr.trim();
    voltageStr.trim();

    // Convert the trimmed strings to float values
    encoder_current = currentStr.toFloat();
    encoder_voltage = voltageStr.toFloat();
  }
}


void setup() {
  Serial.begin(9600);  // Start serial communication at 9600 baud
  while (!Serial)
    ;  // Wait for the serial port to connect - necessary for Leonardo/Micro
  Serial.println("Serial communication started.");

  Wire.begin();  // Join I2C bus
  Serial.println("I2C bus initialized.");
  dacVset.begin(ADDR_DAC_VSET);  // Initialize the VSET DAC
  dacIset.begin(ADDR_DAC_ISET);  // Initialize the ISET DAC
  Wire.begin(ADDR_DISPLAY_SET);  // Join I2C bus with the address for encoder values
  Wire.onReceive(receiveEvent);  // Register event for receiving I2C data
  pinMode(PIN_LED_MCU, OUTPUT);  // Initialize the MCU LED pin as an output

  uint16_t initialIsetDacValue = (uint16_t)((encoder_current / VOLTAGE_PER_STEP) + 0.5);  // Convert an initial current to DAC value
  isetDacValue = initialIsetDacValue;                                                     // Store this initial value in the global variable
  dacIset.setVoltage(isetDacValue, false);                                                // Apply the initial setting

  // Configure INA232
  Serial.println("Configuring INA232...");
  // Set the configuration register to the desired settings
  // Example: continuous shunt and bus voltage measurement with 1 average
  if (writeRegister(INA232_CONFIG, 0x4127)) {
    Serial.println("INA232 configured successfully.");
  } else {
    Serial.println("Failed to configure INA232.");
  }
}

// Function to calculate and set the DAC values for voltage and current
void setVoltageAndCurrent(float voltage, float current) {
  // Calculate DAC value for voltage (VSET)
  // Considering a gain of 15x in the inverting amplifier
  uint16_t vsetDacValue = (uint16_t)((voltage / (VOLTAGE_PER_STEP * 15)) + 0.5);  // Adding 0.5 for rounding to nearest integer

  // Calculate DAC value for current (ISET)
  // 1V corresponds to the full-scale current limit
  uint16_t isetDacValue = (uint16_t)((current / VOLTAGE_PER_STEP) + 0.5);  // Adding 0.5 for rounding to nearest integer

  // Write the DAC values
  dacVset.setVoltage(vsetDacValue, false);
  dacIset.setVoltage(isetDacValue, false);
}

// Function to write a value to the MAX5395
void setPotentiometerWiper(uint8_t wiperValue) {
  Wire.beginTransmission(ADDR_MAX5395);
  Wire.write((uint8_t)0x00);  // Command byte to select the wiper register
  Wire.write(wiperValue);     // Wiper value to set the resistance
  Wire.endTransmission();
}

// Function to convert voltage to resistance and then to wiper position
uint8_t voltageToWiperPosition(float voltage) {
  // Calculate the desired resistance from the voltage
  float desiredResistance = voltage / biasCurrent;

  // If the calculated resistance exceeds the potentiometer's capability, limit it
  if (desiredResistance > maxResistance) {
    desiredResistance = maxResistance;
  }

  // Convert the resistance to a wiper position
  uint8_t wiperPosition = (uint8_t)((desiredResistance / maxResistance) * maxWiperPosition);

  return wiperPosition;
}


void loop() {
  bool readSuccess;
  // Correctly call readRegister with both required arguments
  int16_t shuntVoltage = readRegister(INA232_SHUNT_VOLTAGE, readSuccess);

  if (!readSuccess) {
    Serial.println("Failed to read shunt voltage.");  // Handle the failure case
  } else {
    // If read was successful, proceed with using the shuntVoltage
    float current = shuntVoltage * currentResolution;
    Serial.print("Current: ");
    Serial.print(current);
    Serial.println(" A");
  }

  // Set the desired voltage and current
  setVoltageAndCurrent(encoder_voltage, encoder_current);

  // Convert voltage to wiper position
  uint8_t wiperPosition = voltageToWiperPosition(encoder_voltage);

  // Set the potentiometer wiper to achieve the desired voltage
  setPotentiometerWiper(wiperPosition);

  adjustCurrent();  // Adjust the current based on encoder input and actual measurement

  // Toggle LED to indicate operation
  digitalWrite(PIN_LED_MCU, HIGH);
  delay(500);
  digitalWrite(PIN_LED_MCU, LOW);

  delay(1000);  // Wait for 1 second before the next iteration
}



bool writeRegister(uint8_t reg, uint16_t value) {
  Wire.beginTransmission(INA232_ADDRESS);
  Wire.write(reg);
  Wire.write((value >> 8) & 0xFF);       // MSB
  Wire.write(value & 0xFF);              // LSB
  byte result = Wire.endTransmission();  // Execute the transmission and capture the result
  return result == 0;                    // Return true if transmission was successful, false otherwise
}


int16_t readRegister(uint8_t reg, bool& success) {
  Wire.beginTransmission(INA232_ADDRESS);
  Wire.write(reg);
  if (Wire.endTransmission(false) != 0) {
    success = false;  // Indicate failure
    return 0;         // Early exit on transmission failure
  }
  Wire.requestFrom(static_cast<uint8_t>(INA232_ADDRESS), static_cast<uint8_t>(2));
  if (Wire.available() < 2) {
    success = false;  // Indicate failure if not enough data is available
    return 0;         // Early exit on data availability issue
  }
  success = true;                     // Indicate success
  uint16_t value = Wire.read() << 8;  // MSB
  value |= Wire.read();               // LSB
  return (int16_t)value;
}

void adjustCurrent() {
  bool readSuccess;
  // Correctly call readRegister with the updated signature
  int16_t shuntVoltage = readRegister(INA232_SHUNT_VOLTAGE, readSuccess);

  if (!readSuccess) {
    Serial.println("Error reading shunt voltage.");
    return;  // Early exit if read operation failed
  }

  // Proceed with using shuntVoltage for calculations
  float actual_current = shuntVoltage * currentResolution;
  // Calculate the difference between desired and actual current
  float current_difference = encoder_current - actual_current;

  // Proportional adjustment based on the difference
  int adjustment = (int)(Kp * current_difference * DAC_RESOLUTION / VREF);

  // Apply limits to isetDacValue to ensure it's within DAC range and safety limits
  isetDacValue += adjustment;
  isetDacValue = max(0, min(isetDacValue, DAC_RESOLUTION - 1));
  float proposedCurrent = isetDacValue * VOLTAGE_PER_STEP;
  if (proposedCurrent > MAX_CURRENT) {
    isetDacValue = (int)(MAX_CURRENT * DAC_RESOLUTION / VREF);
  }

  // Apply the adjusted DAC value
  dacIset.setVoltage(isetDacValue, false);
  Serial.print("Adjusted DAC Value for ISET: ");
  Serial.println(isetDacValue);
}

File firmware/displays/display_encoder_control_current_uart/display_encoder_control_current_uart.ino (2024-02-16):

#include "DFRobot_LedDisplayModule.h"
#include <Wire.h>

/*
ENCODER

2 PIN side
- UPPER to DIG4
- LOWER to GND

3 PIN side
- UPPER to DIG3
- MIDDLE to GND
- LOWER to DIG2

Display
- SDA -  A4 ROHELINE
- SCL - A5 SININE

Current
const int encoderPin1 = 2;
const int encoderPin2 = 3;
const int encoderSwitchPin = 4;  // Push button switch of the encoder

Voltage
const int encoderPin1 = 6;
const int encoderPin2 = 7;
const int encoderSwitchPin = 8;  // Push button switch of the encoder

*/

// Initialize with the correct I2C address
DFRobot_LedDisplayModule LED(&Wire, 0x48);

// Rotary Encoder Pins
const int encoderPin1 = 2;
const int encoderPin2 = 3;
const int encoderSwitchPin = 4;  // Push button switch of the encoder

volatile int lastEncoded = 0;
volatile long encoderValue = 0;
long lastencoderValue = 0;
int lastMSB = 0;
int lastLSB = 0;

void setup() {
  Serial.begin(9600); // have to be the same as the baud rate of the ATmega32U4
  Wire.begin();  // Start I2C communication

  // Setup encoder pins
  pinMode(encoderPin1, INPUT_PULLUP);
  pinMode(encoderPin2, INPUT_PULLUP);
  pinMode(encoderSwitchPin, INPUT_PULLUP);

  // Setup interrupts for rotary encoder
  attachInterrupt(digitalPinToInterrupt(encoderPin1), updateEncoder, CHANGE);
  attachInterrupt(digitalPinToInterrupt(encoderPin2), updateEncoder, CHANGE);

  // Setup the display
  while (LED.begin(LED.e4Bit) != 0) {
    Serial.println("Failed to initialize the chip, please confirm the chip connection!");
    delay(1000);
  }
  LED.setDisplayArea(1, 2, 3, 4);
  LED.setBrightness(2);

  // Display initial value
  displayNumber(0);  // Start with 0.00 on display
}

void loop() {
  static long lastDisplayValue = -1;  // Store the last displayed value to update only on changes

  if (digitalRead(encoderSwitchPin) == LOW) {
    // Reset the value if the encoder switch is pressed
    encoderValue = 0;
  }

  // Calculate the display value based on encoder value
  float displayVal = encoderValue * 0.02;           // Example step of 0.05 per encoder step
  displayVal = max(0.02, min(displayVal, 3.00));  // Constrain between 0.00 and 3.00

  if (lastDisplayValue != encoderValue) {
    // Update the display only if the value has changed
    lastDisplayValue = encoderValue;
    displayNumber(displayVal);
    Serial.println(displayVal);
  }

  delay(50);  // Debounce delay
}

void displayNumber(float value) {
  // Format and display the value on the LED display
  int whole = (int)value;                     // Whole part
  float decimalPart = (value - whole) * 100;  // Decimal part as float to apply rounding correctly

  // Apply a rounding fix for the decimal part
  int decimal = (int)(decimalPart + 0.5);  // Adding 0.5 before casting to int rounds the decimal part

  // Ensure that after rounding, the decimal part does not exceed 99
  if (decimal >= 100) {
    whole += 1;      // Increment the whole part if rounding the decimal exceeds 99
    decimal -= 100;  // Adjust the decimal part back to 0 after incrementing the whole part
  }

  // Preparing to display numbers with correct formatting
  if (whole == 0) {
    // Special case for displaying "0."
    LED.print("", "0.", String(decimal / 10).c_str(), String(decimal % 10).c_str());
  } else {
    // For other numbers, dynamically build the string based on the whole and decimal parts
    char formattedNumber[6];  // Including space for null terminator
    sprintf(formattedNumber, "%2d.%02d", whole, decimal);

    // Break down the formatted string into displayable parts
    String part1 = (formattedNumber[0] == ' ') ? "" : String(formattedNumber[0]);
    String part2 = (formattedNumber[1] == '0' && whole < 10) ? "0." : String(formattedNumber[1]) + ".";
    String part3 = String(formattedNumber[3]);
    String part4 = String(formattedNumber[4]);

    // Send parts to the display function
    LED.print(part1.c_str(), part2.c_str(), part3.c_str(), part4.c_str());
  }

  // Debug output to serial monitor
  Serial.print("Displaying: ");
  if (whole == 0) {
    Serial.print(" 0.");
  } else {
    Serial.print(whole);
    Serial.print('.');
  }
  Serial.println(decimal);
}

void updateEncoder() {
  int MSB = digitalRead(encoderPin1);  // Most significant bit
  int LSB = digitalRead(encoderPin2);  // Least significant bit

  int encoded = (MSB << 1) | LSB;          // Converting the 2 pin value to single number
  int sum = (lastEncoded << 2) | encoded;  // Adding it to the previous encoded value

  if (sum == 0b1101 || sum == 0b0100 || sum == 0b0010 || sum == 0b1011) encoderValue++;
  if (sum == 0b1110 || sum == 0b0111 || sum == 0b0001 || sum == 0b1000) encoderValue--;

  lastEncoded = encoded;  // Store this value for next time
}

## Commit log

2023-10-04 electronics: added initial schematics
    [DCSupplyHub.PrjPcb, DCSupplyHub.SchDoc]
2023-10-04 electronics: added useful libraries from previous projects
    [MotorDriver.SCHLIB]
2023-10-10 eletronics: added schematics with initial logic and components (inc resistors, caps, etc..)
    [DCSupplyHub.SchDoc]
2023-10-15 electronics: added II version of schematics
    - divided the schematics on 3 different A4s
    - modified the grid size
    - modified fuse symbol and designator
    - flipped J4 on Y-axis and added references for + and -
    - added reset pull up cap and resistor with reset button to MCU
    - added micro-USB for programming MCU
    - some minor schematics and symbol fixes
    [DCSupplyHub.PrjPcb, DCSupplyHub.SchDoc, v2-DCSupplyHub-current.SchDoc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]
2023-10-24 electronics: created lib based on project components, made minor modifications in schematics
    [DCSupplyHub.SchDoc, DCSupplyHubLib.SchLib, DCSupplyHupLib.PcbLib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]
2023-11-05 added second version of schematics
    1. Changed the fuse symbol
    2. Changed components style
    3. Replaced MCU pins
    4. There were 3 different capacitor symbols on schematics, now 1
    5. Changed VCC and 3.3V symbols
    6. Placed ports and changed some net labels
    7. Added datasheet links under parameters
    8. In II version used LTC3649 and LT3080 for feedback and power control
    9. Maybe right now the old sensing sheet is useless?
    [DCSupplyHub.PrjPcb, DCSupplyHubLib.SchLib, DCSupplyHupLib.PcbLib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]
2023-11-05 electronics: minor edits
    [v2-DCSupplyHub-sensing.SchDoc, v2-DCSupplyHub.SchDoc]
2023-11-05 eletronics: added annotation
    [v2-DCSupplyHub-outputs.SchDoc, v2-DCSupplyHub-sensing.SchDoc, v2-DCSupplyHub.SchDoc]
2023-11-06 electronics: changes in sensing and output
    [v2-DCSupplyHub-outputs.SchDoc, v2-DCSupplyHub-sensing.SchDoc]
2023-11-07 electronics: fixed entrypoint logic
    - MCU programmer
    - J1 symbol
    - Power in wasn't connected to power
    - Added DC-DC/EPOT and PWN DAC and PSU beginnings
    [DCDC-EPOT.SchDoc, LOG.SchDoc, PWM-DAC-PSU.SchDoc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]
2023-11-08 electronics: major updates
    - updated sensing schematics
    - updated main entrypoint schematics with ports and new encoder symols
    - updated DC-DC and EPOT schematics
    [DCDC-EPOT.SchDoc, DCSupplyHubLib.SchLib, PWM-DAC-PSU.SchDoc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]
2023-11-09 electronics: fixed all errors in schematics
    - added OLED connector
    - fixed net labels
    - fixed designators
    [DCDC-EPOT.SchDoc, PWM-DAC-PSU.SchDoc, v2-DCSupplyHub-outputs.SchDoc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]
2023-11-10 electronics: added final schematics
    - added ESD protections
    - added no ERC pins
    - added connectors to components that are connected with wires
    - added missing footprints
    - fixed all schematic errors and warnings
    [DCDC-EPOT.SchDoc, DCSupplyHubLib.SchLib, DCSupplyHupLib.PcbLib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]
2023-11-10 electronics: added docs + minor updates
    - updated LOG
    - added cap for programming MCU
    [LOG.SchDoc, PWM-DAC-PSU.SchDoc, v2-DCSupplyHub.SchDoc]
2023-11-10 pcb: added all missing footprints
    [DCDC-EPOT.SchDoc, DCSupplyHub.PcbDoc, DCSupplyHub.PrjPcb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]
2023-11-13 electronics: added initial PCB design
    [DCSupplyHub.PcbDoc, PWM-DAC-PSU.SchDoc, v2-DCSupplyHub.SchDoc]
2023-11-13 pcb: minor track and text updates
    [DCSupplyHub.PcbDoc]
2023-11-13 pcb: added GND plane with vias
    [DCSupplyHub.PcbDoc]
2023-11-13 electronics: pcb rule updates, pcb updates
    [DCSupplyHub.PcbDoc, v2-DCSupplyHub.SchDoc]
2023-11-13 schematics: fixed pol cap and added i2c pullup resistors
    [PWM-DAC-PSU.SchDoc, v2-DCSupplyHub.SchDoc]
2023-11-13 schematics: fixed LT3080 parallel connections
    did all 3 LT3080 as was U13 before
    [DCSupplyHub.PcbDoc, PWM-DAC-PSU.SchDoc]
2023-11-14 schematics: updated LT3080 parallel connection
    [PWM-DAC-PSU.SchDoc]
2023-11-14 schematics: updated LT3080 parallel connection and annotation
    [PWM-DAC-PSU.SchDoc]
2023-11-14 schematics: minor grid edits
    [PWM-DAC-PSU.SchDoc]
2023-11-14 schematics: fixed LM3080 feedback loop, deleted ADC-VOUT net
    [PWM-DAC-PSU.SchDoc]
2023-11-15 PCB: updated I version of routed PCB
    [DCSupplyHub-v2.PcbDoc, DCSupplyHub.PcbDoc, DCSupplyHub.PrjPcb]
2023-11-15 electronics: made small adjustment to program MCU, added GND plane
    [DCSupplyHub-v2.PcbDoc, PWM-DAC-PSU.SchDoc, v2-DCSupplyHub.SchDoc]
2023-11-21 schematics: fixed CV nets, added comments
    [DAC.SchDoc, DCDC-EPOT.SchDoc, DCSupplyHub-v2.PcbDoc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]
2023-11-22 schematics: updated power in of the schematics
    [v2-DCSupplyHub.SchDoc]
2023-11-23 added DAC, removed low voltage adjuster
    [DCDC-EPOT.SchDoc, DCSupplyHub.PcbDoc]
2023-11-23 schematics: added DAC for ISET
    [DAC-VCONV.SchDoc, DCSupplyHub.PrjPcb, DCSupplyHubLib.SchLib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]
2023-11-23 schematics: added missing bypass caps
    [DCSupplyHub-v2.PcbDoc, DCSupplyHub.PrjPcb, DCSupplyHubLib.SchLib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]
2023-11-23 schematics: minor fixes
    [PWM-DAC-PSU.SchDoc, v2-DCSupplyHub.SchDoc]
2023-11-23 docs: added comments on schematics
    [DCSupplyHub-v2.PcbDoc, v2-DCSupplyHub.SchDoc]
2023-11-23 schematics: annotation error fixed
    [PWM-DAC-PSU.SchDoc, v2-DCSupplyHub.SchDoc]
2023-11-23 pcb: fixed button footprint
    [v2-DCSupplyHub.SchDoc]
2023-11-26 schematics: uploaded IV version
    1. Refactored schematics - added output&ext-modules sheet for external modules and outputs.
    2. Changed X2 caps value
    3. Changed J1 designator
    4. Changed 3.3V and 5V LDOs
    5. Changed position of USB connector
    6. Fixed USB connector circuit to program MCU
    7. Took away VBUS cap
    8. Changed 18k resistors to 9k
    9. Removed reverse protection diode between input and output
    [DCSupplyHub.PrjPcb, DCSupplyHubLib.SchLib, LOG.SchDoc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]
2023-11-26 schematics: fixed errors
    [LOG.SchDoc, PWM-DAC-PSU.SchDoc, VCONV-DAC.SchDoc]
2023-12-04 schematics: changed voltage adjusting logic
    [DCSupplyHubLib.SchLib, PWM-DAC-PSU.SchDoc, VCONV-DAC.SchDoc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]
2023-12-04 schematics: fixed schematic errors
    [PWM-DAC-PSU.SchDoc, VCONV-DAC.SchDoc, output&ext-modules.SchDoc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]
2023-12-04 schematics: fixed port errors and set port directions
    [PWM-DAC-PSU.SchDoc, output&ext-modules.SchDoc, v2-DCSupplyHub.SchDoc]
2023-12-04 schematics: added notes about components on the schematic
    [PWM-DAC-PSU.SchDoc, VCONV-DAC.SchDoc]
2023-12-04 schematics: modified +30V_CV net name to +30V_ADJ
    [PWM-DAC-PSU.SchDoc, VCONV-DAC.SchDoc]
2023-12-04 schematics: added operating currents
    [PWM-DAC-PSU.SchDoc, output&ext-modules.SchDoc, v2-DCSupplyHub.SchDoc]
2023-12-04 schematics: adjusted comments
    [PWM-DAC-PSU.SchDoc, v2-DCSupplyHub.SchDoc]
2023-12-04 docs: added logs to LOG.SchDoc
    [LOG.SchDoc, output&ext-modules.SchDoc]
2023-12-04 schematics: fixed missing symbol graphic
    [LOG.SchDoc, VCONV-DAC.SchDoc]
2023-12-04 schematics: disabled cross references
    [VCONV-DAC.SchDoc]
2023-12-05 updated schematic and pcb libraries
    [DCSupplyHub.PrjPcb, DCSupplyHubLib.SchLib]
2023-12-05 updated resistors value to TBC
    [VCONV-DAC.SchDoc]
2023-12-05 schematics: added power dissipation calculations
    [PWM-DAC-PSU.SchDoc, VCONV-DAC.SchDoc, output&ext-modules.SchDoc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]
2023-12-05 schematics: updated LTC3649 resistor values
    [VCONV-DAC.SchDoc, v2-DCSupplyHub.SchDoc]
2023-12-06 pcb: added new version of PCB, modified components to not have any layers on Mechanical 1 layer. Added initial power tracks.
    [DCSupplyHub-v2_20231205a.PcbDoc]
2023-12-06 added new version of PCB
    [DCSupplyHub-v2_20231205a.PcbDoc]
2023-12-06 pcb: updated text on PCB
    [DCSupplyHub.PrjPcb]
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2023-12-06 fix: fixed fuse led indicator circuit error, renamed MCU LED net and added 2 more caps to MCU VCC
    [v2-DCSupplyHub.SchDoc]
2023-12-06 schematics: fixed buck converter schematics, added few components
    [DCSupplyHubLib.SchLib, VCONV-DAC.SchDoc, v2-DCSupplyHub.SchDoc]
2023-12-06 schematics: updated inductor value
    [v2-DCSupplyHub.SchDoc]
2023-12-06 pcb: updated inductor footprint
    [DCSupplyHubLib.SchLib, VCONV-DAC.SchDoc]
2023-12-06 updated U9 according to datasheet
    [VCONV-DAC.SchDoc]
2023-12-07 updated inductor footprint
    [VCONV-DAC.SchDoc]
2023-12-07 updated inductor symbol and footprint
    [DCSupplyHubLib.SchLib, VCONV-DAC.SchDoc]
2023-12-07 added PDF of schematics
    [VCONV-DAC.SchDoc]
2023-12-07 pcb: new version with fixed schematics
    [DCSupplyHub.PrjPcb]
2023-12-10 schematics: fixed USB resistors position
    [v2-DCSupplyHub.SchDoc]
2023-12-11 schematics: updated 3D model, updated resistor position of USB, took out R25
    [DCSupplyHub.PrjPcb, PWM-DAC-PSU.SchDoc, output&ext-modules.SchDoc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]
2023-12-12 schemaitcs: added resistor to USB output, fixed bypass caps errors
    [DCSupplyHub-v2.PcbDoc, DCSupplyHubLib.SchLib, LOG.SchDoc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]
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2023-12-13 PCB: modified PCB
    - Modified +30V_ADJ track width
    - Modified bypass caps. added one more to MCU
    - Added one resistor to limit output USB current
    - Added TO-220 package to 5V LDO and heatsink
    [DCSupplyHub.PrjPcb, v2-DCSupplyHub.SchDoc]
2023-12-13 PCB: added gerber files
    [DCSupplyHub-v2_20231213b.GBL, DCSupplyHub-v2_20231213b.GBO, DCSupplyHub-v2_20231213b.GBP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]
2023-12-13 PCB: fixed mechanical 1 layer, added heatsinks 3D files
    [DCSupplyHub.PrjPcb, v2-DCSupplyHub.SchDoc]
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
